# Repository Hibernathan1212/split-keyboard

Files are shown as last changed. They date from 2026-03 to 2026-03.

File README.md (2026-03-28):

# SPlitty

An ergonomic ortholinear split keyboard made to be low profile yet enjoyable and comfortable to use. It features a 6 column by 3 row layout similar to the Corne ergo keyboard but instead with a full width bottom "thumb cluster" that hopefully helps in moving from a traditional keyboard to a split ergo thumb cluster. This is mostly based around many of my current workflows being based around using CMD CTRL and ALT together on my mac so I wanted a way to reliably (no mod tap/hold on home row) press all of them while pressing all the other keys. I have an absolem/voyager style sticking out thumb cluster which allows for a more natural open hand. I wanted to make this project to help with the uncomfortable ergonomics of my desk that make me hunch forward to my keyboard whereas I'd rather my arms be further apart.

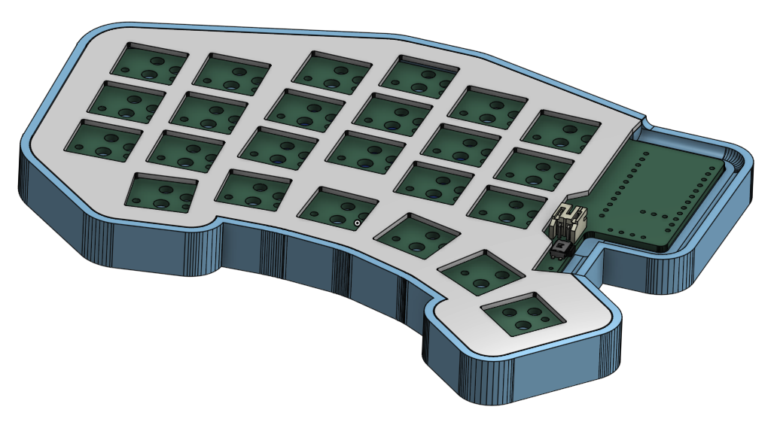
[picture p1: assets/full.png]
full


## Features

- Ortholinear
- Column staggered
- 48 keys
- Pinky splay
- 128x32 OLED Displays
- Customizable tilt with tent legs
- ZMK Firmware
- Low Profile Choc Linear Switches
- Wireless
- Hotswappable

## CAD

Uses a mix between a floating tray mount (resting on top of pillars) and a floating integrated plate on a lip to get the benefits of rigidity from tray mount without being too rigid and also alignment from plate.

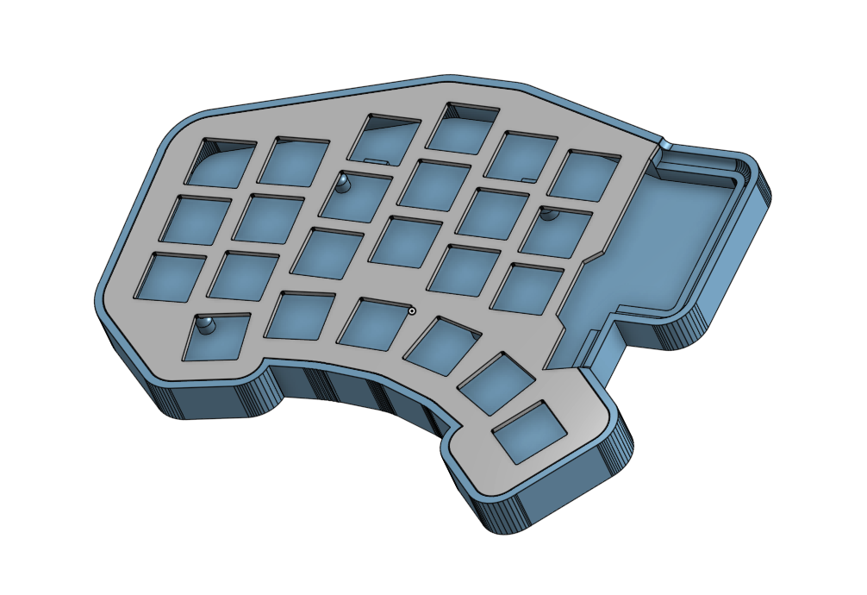
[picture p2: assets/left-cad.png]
Left

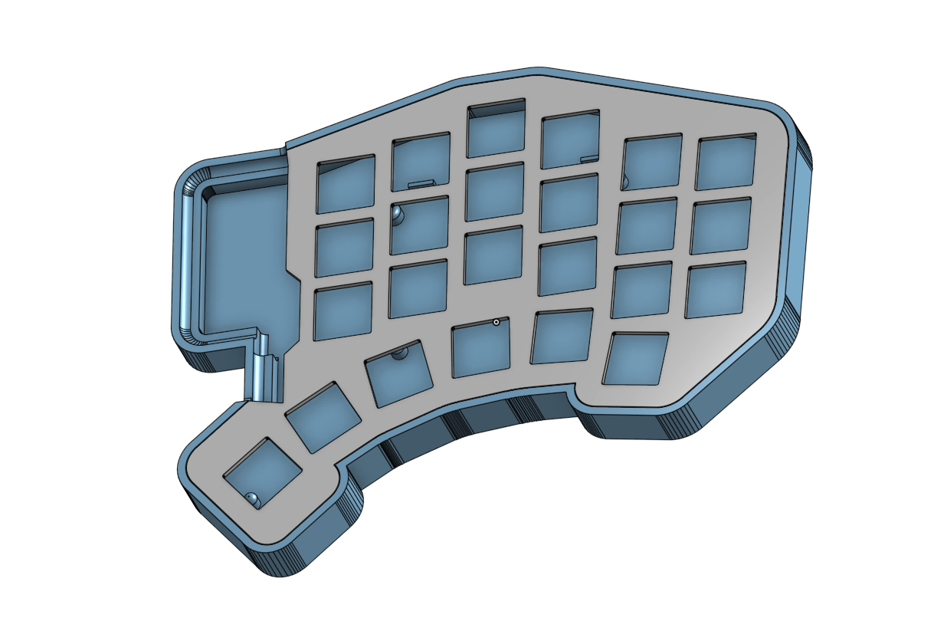
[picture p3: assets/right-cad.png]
Right


Made in Onshape.

## PCB

Made in Kicad

### Schematic

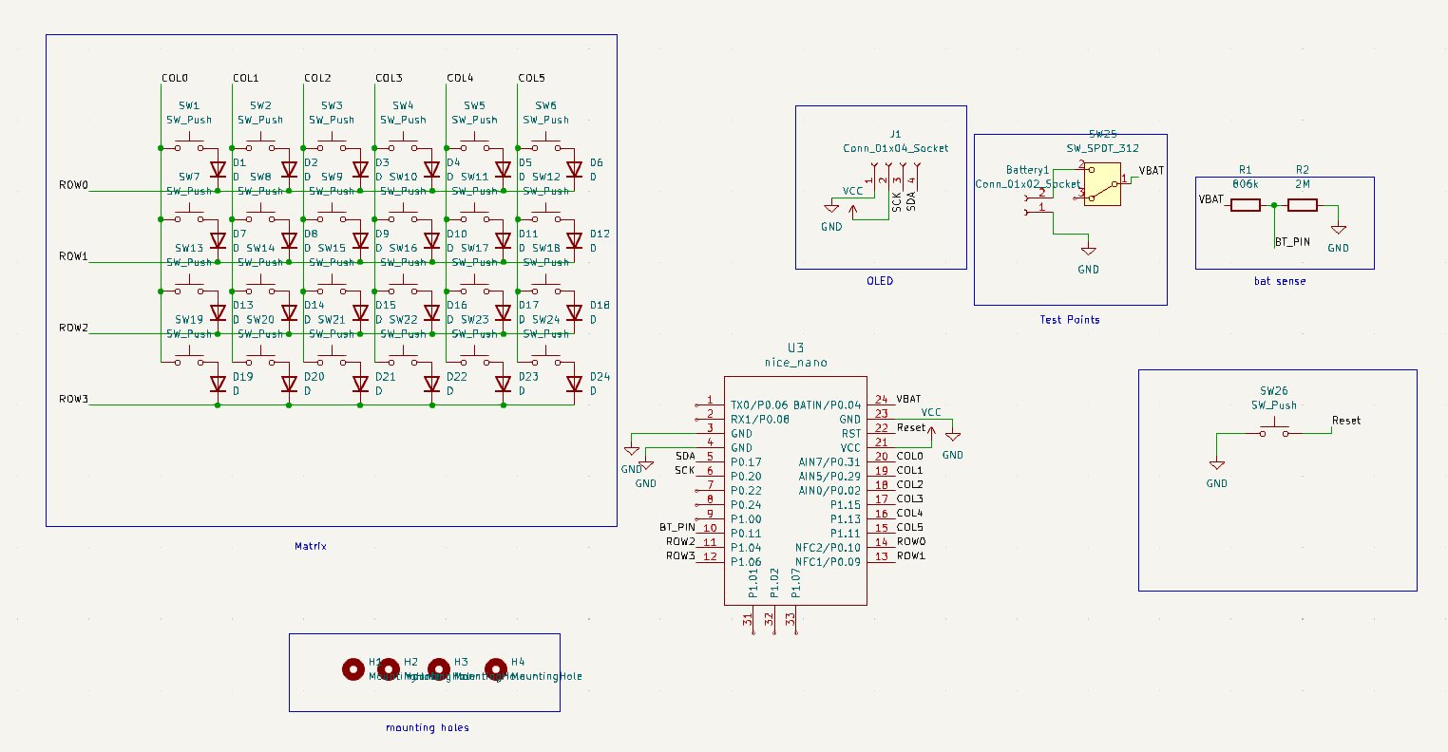
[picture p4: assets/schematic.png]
schematic


### PCB

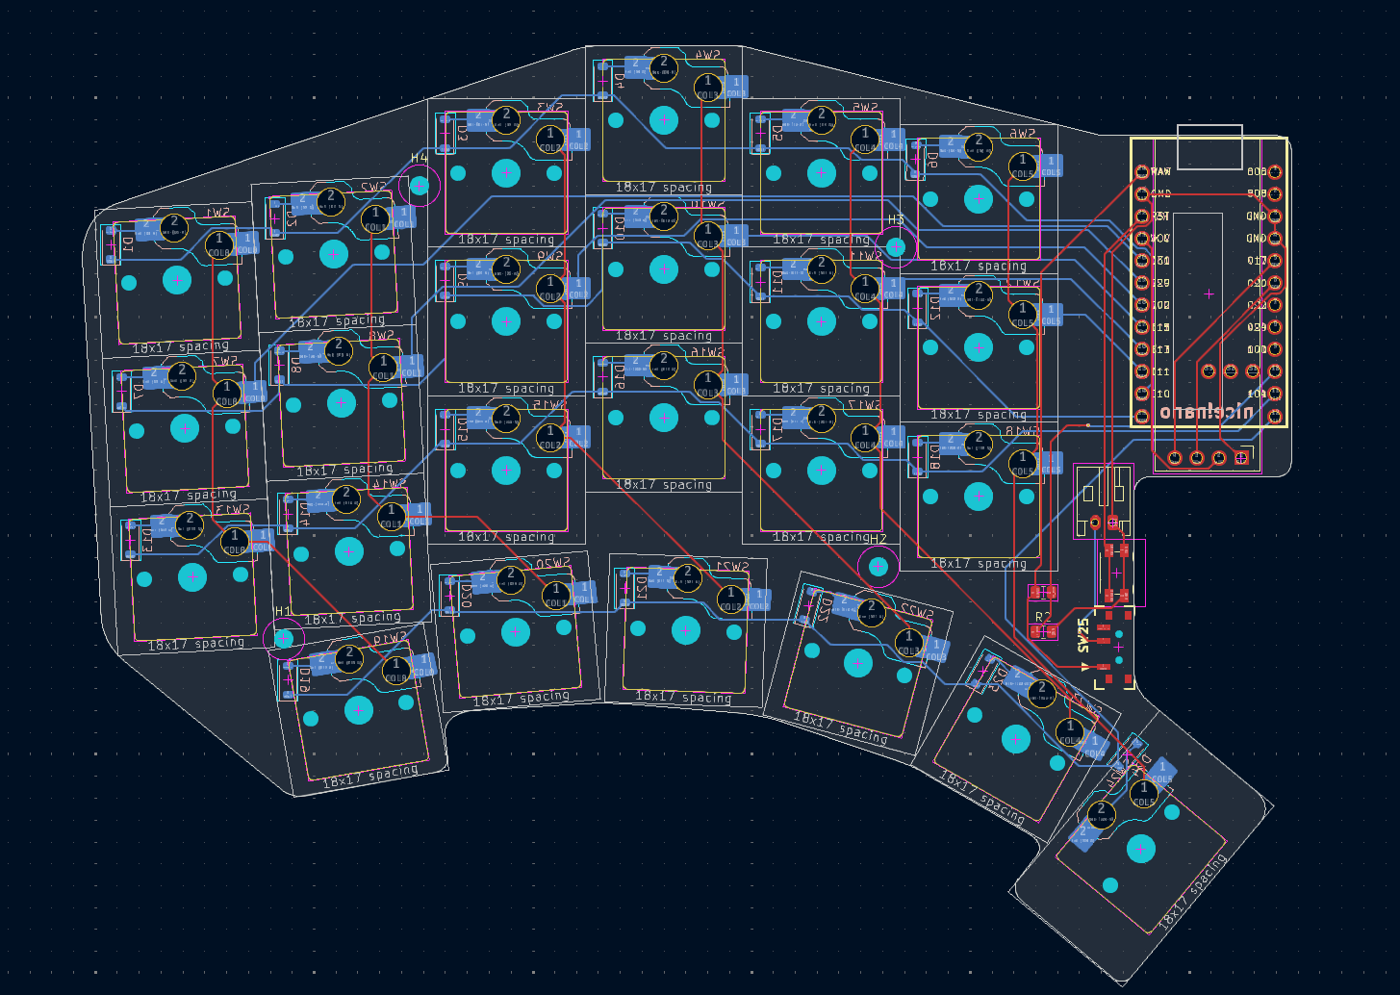
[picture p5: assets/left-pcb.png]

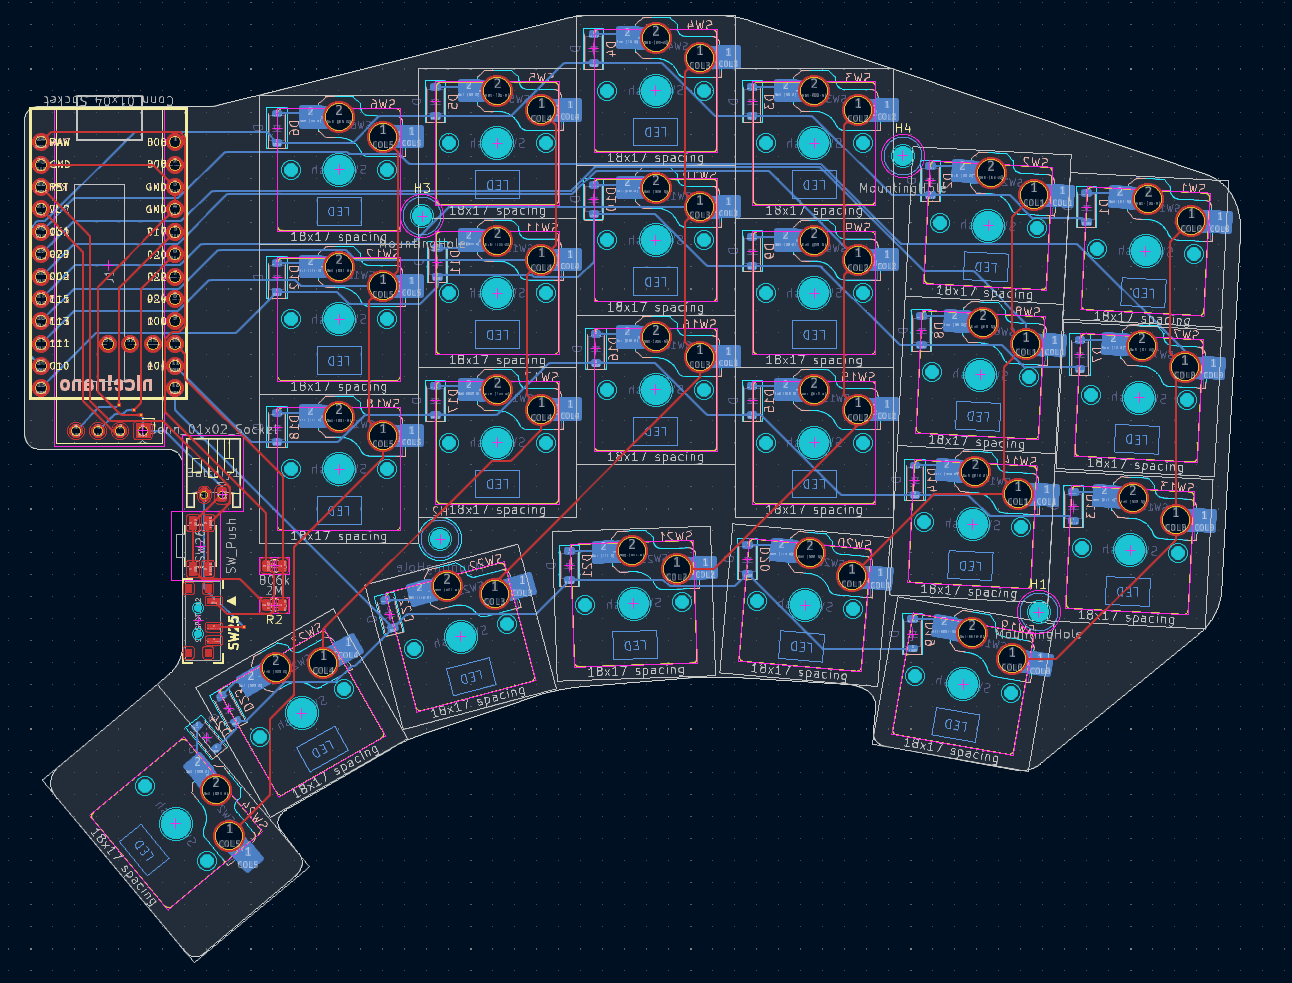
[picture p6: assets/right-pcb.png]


## Firmware

Uses ZMK and is customizable to do whatever you want pretty much. Set up to work with ZMK Studio. By default has 4 layers: the default qwerty layout layer, a numpad & function keys layout, a symbols layer, and a nav layer with mouse movements.

## BOM

| Product | Amount | Unit Cost (THB) | Price (THB) | Price (USD) | Link |
| --- | --- | --- | --- | --- | --- |
| Kailh Choc Low Profile Switches V1  | 70 | 791.58 | 791.58 | 24.09 | [https://th.aliexpress.com/item/1005005723938995.html](https://th.aliexpress.com/item/1005005723938995.html) |
| Kailh Choc Low Profile Keycaps 1u | 5\*10  | 135 | 675 | 20.54 | [https://keebd.com/products/ldsa-low-profile-blank-keycaps?variant=43210374185112](https://keebd.com/products/ldsa-low-profile-blank-keycaps?variant=43210374185112) |
| Kailh Choc Low Profile Keycaps 1.5u | 1\*2 | 51 | 51 | 1.55 | [https://keebd.com/products/ldsa-low-profile-blank-keycaps?variant=43210375397528](https://keebd.com/products/ldsa-low-profile-blank-keycaps?variant=43210375397528) |
| Choc Hotswap Sockets | 50 | 177.03 | 177.03 | 5.39 | [https://th.aliexpress.com/item/1005008543325730.html](https://th.aliexpress.com/item/1005008543325730.html) |
| Reset Button | 2 | 51 | 102 | 3.1 | [https://keebd.com/products/reset-button-panasonic](https://keebd.com/products/reset-button-panasonic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) |
| Power Switch | 2 | 26 | 52 | 1.58 | [https://keebd.com/products/switch-mini-7-pin-2-slide-positions](https://keebd.com/products/switch-mini-7-pin-2-slide-positions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) |
| Rubber Feet | 4 | 73.6 | 73.6 | 2.24 | [https://th.aliexpress.com/item/1005007438396940.html](https://th.aliexpress.com/item/1005007438396940.html) |
| Tenting Feet | 4 | 58.83 | 235.32 | 7.16 | [https://th.aliexpress.com/item/1005011724480659.html](https://th.aliexpress.com/item/1005011724480659.html) |
| 403450 750mAh | 2 | 130.24 | 260.48 | 7.93 | [https://th.aliexpress.com/item/1005003630012646.html](https://th.aliexpress.com/item/1005003630012646.html) |
| Battery JST PH Connector | 2 | 51 | 102 | 3.1 | [https://keebd.com/products/jst-power-connector](https://keebd.com/products/jst-power-connector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) |
| ProMicro nrf52840 Board | 2 | 106.15 | 212.3 | 6.46 | [https://th.aliexpress.com/item/1005006271779544.html](https://th.aliexpress.com/item/1005006271779544.html) |
| Diodes | 1 | 25.78 | 25.78 | 0.78 | [https://th.aliexpress.com/item/1005008826378208.html](https://th.aliexpress.com/item/1005008826378208.html) |
| Oled Display 0.91inch I2C | 1 | 155.34 | 155.34 | 4.73 | [https://th.aliexpress.com/item/1005008918700196.html](https://th.aliexpress.com/item/1005008918700196.html) |
| PCB left | 1 | | | 10 | |
| PCB right | 1 | | | 10 | |
| | | | | | |
| aliexpress shipping | | | 143.8 | 4.38 | |
| keebd shipping | | | 230 | 7 | |
| jlcpcb shipping | | | | 0.05 | |
| | | | | | |
| Total | | | | 120.08 | |

(If anyone could help source cheaper materials it would be greatly appreciated)

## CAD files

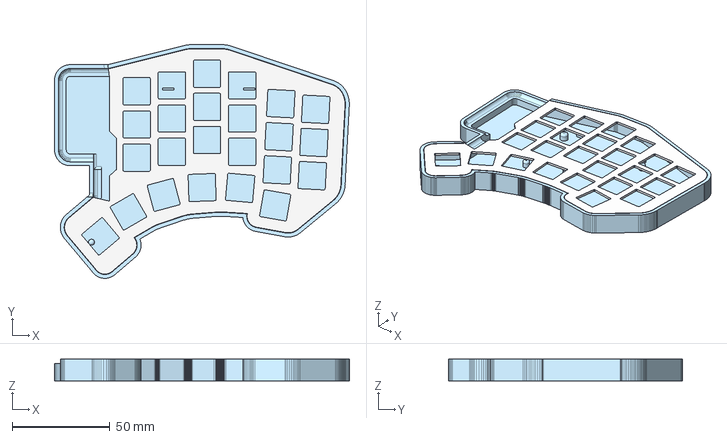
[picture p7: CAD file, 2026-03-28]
cad/assembled right.step
151.0 x 119.7 x 11.2 mm

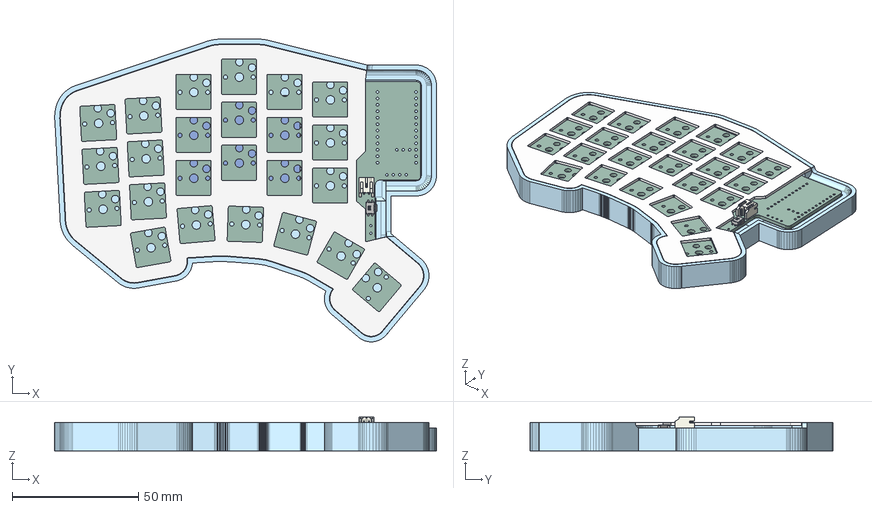
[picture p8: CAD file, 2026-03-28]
cad/Assembled w PCB.step
151.0 x 119.7 x 13.4 mm
D_SOD-123 x 24
R_0805_2012Metric x 2
JST_PH_S2B-PH-K_1x02_P2.00mm_Horizontal
split-keyboard_PCB
Panasonic_EVQPUJ_EVQPUA

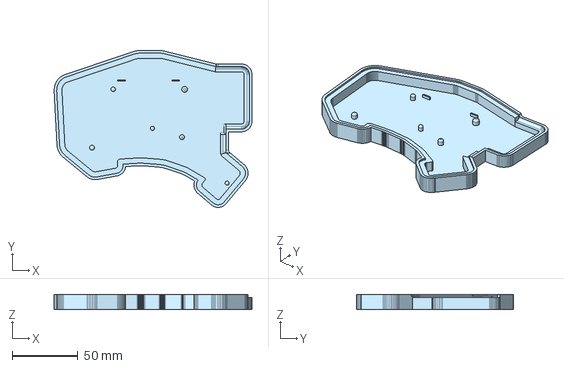
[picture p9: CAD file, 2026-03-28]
production/base left.step
151.0 x 119.7 x 11.2 mm

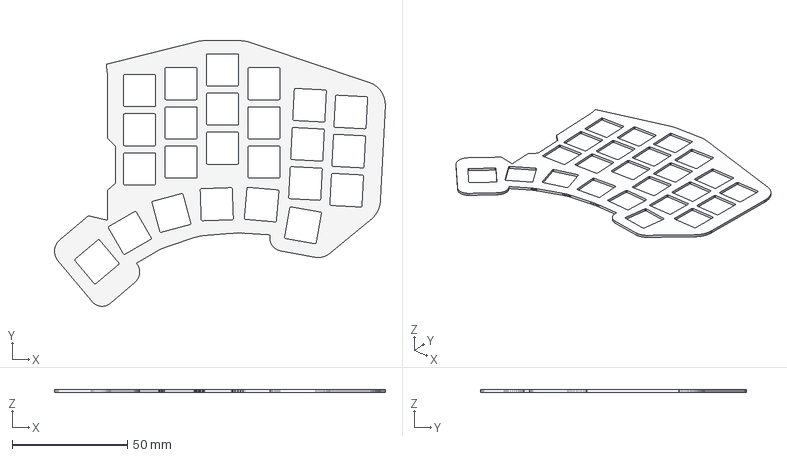
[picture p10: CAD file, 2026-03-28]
production/top right.step
143.7 x 115.3 x 1.20 mm

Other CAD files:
cad/assembled left.step
production/top left.step
production/base right.step

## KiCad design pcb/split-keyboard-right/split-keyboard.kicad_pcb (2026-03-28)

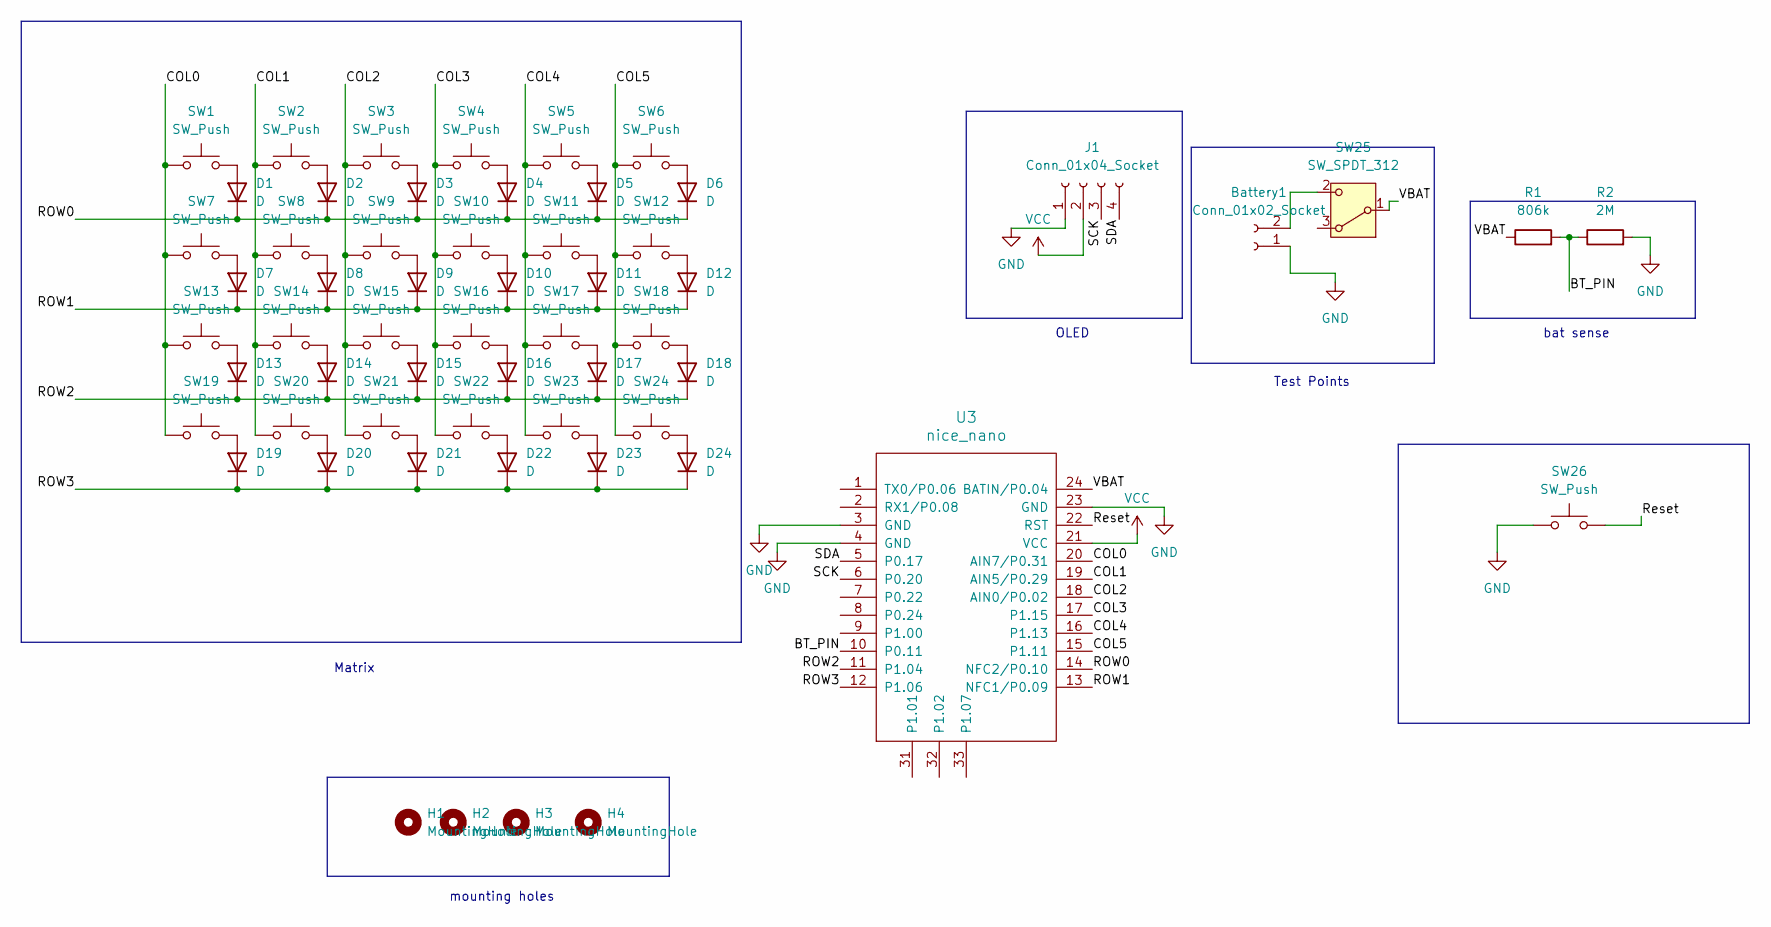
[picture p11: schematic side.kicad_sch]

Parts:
Battery1: Conn_01x02_Socket; JST_PH_S2B-PH-K_1x02_P2.00mm_Horizontal
D1, D2, D3, D4, D5, D6, D7, D8, D9, D10, D11, D12, D13, D14, D15, D16, D17, D18, D19, D20, D21, D22, D23, D24: D; D_SOD-123
H1, H2, H3, H4: MountingHole; MountingHole_2.2mm_M2
J1: Conn_01x04_Socket; ER_OLEDM0.91_1x-I2C
R1: 806k; R_0805_2012Metric
R2: 2M; R_0805_2012Metric
SW1, SW2, SW3, SW4, SW5, SW6, SW7, SW8, SW9, SW10, SW11, SW12, SW13, SW14, SW15, SW16, SW17, SW18, SW19, SW20, SW21, SW22, SW23: SW_Push; SW_choc_v1_HS_CPG135001S30_1u
SW24: SW_Push; SW_choc_v1_HS_CPG135001S30_1.5u
SW25: SW_SPDT_312; ALPS_SSSS811101
SW26: SW_Push; Panasonic_EVQPUJ_EVQPUA
U3: nice_nano

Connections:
/left/BT_PIN: R1.2, R2.1, U3.10 (P0.11)
/left/COL0: SW1.1, SW7.1, SW13.1, SW19.1, U3.20 (AIN7/P0.31)
/left/COL1: SW2.1, SW8.1, SW14.1, SW20.1, U3.19 (AIN5/P0.29)
/left/COL2: SW3.1, SW9.1, SW15.1, SW21.1, U3.18 (AIN0/P0.02)
/left/COL3: SW4.1, SW10.1, SW16.1, SW22.1, U3.17 (P1.15)
/left/COL4: SW5.1, SW11.1, SW17.1, SW23.1, U3.16 (P1.13)
/left/COL5: SW6.1, SW12.1, SW18.1, SW24.1, U3.15 (P1.11)
/left/ROW0: D1.1 (K), D2.1 (K), D3.1 (K), D4.1 (K), D5.1 (K), D6.1 (K), U3.14 (NFC2/P0.10)
/left/ROW1: D7.1 (K), D8.1 (K), D9.1 (K), D10.1 (K), D11.1 (K), D12.1 (K), U3.13 (NFC1/P0.09)
/left/ROW2: D13.1 (K), D14.1 (K), D15.1 (K), D16.1 (K), D17.1 (K), D18.1 (K), U3.11 (P1.04)
/left/ROW3: D19.1 (K), D20.1 (K), D21.1 (K), D22.1 (K), D23.1 (K), D24.1 (K), U3.12 (P1.06)
/left/Reset: SW26.2, U3.22 (RST)
/left/SCK: J1.3, U3.6 (P0.20)
/left/SDA: J1.4, U3.5 (P0.17)
/left/VBAT: R1.1, SW25.1 (B), U3.24 (BATIN/P0.04)
GND: Battery1.1, J1.1, R2.2, SW26.1, U3.3 (GND), U3.4 (GND), U3.23 (GND)
unnamed: Battery1.2, SW25.2 (C)
unnamed: D1.2 (A), SW1.2
unnamed: D2.2 (A), SW2.2
unnamed: D3.2 (A), SW3.2
unnamed: D4.2 (A), SW4.2
unnamed: D5.2 (A), SW5.2
unnamed: D6.2 (A), SW6.2
unnamed: D7.2 (A), SW7.2
unnamed: D8.2 (A), SW8.2
unnamed: D9.2 (A), SW9.2
unnamed: D10.2 (A), SW10.2
unnamed: D11.2 (A), SW11.2
unnamed: D12.2 (A), SW12.2
unnamed: D13.2 (A), SW13.2
unnamed: D14.2 (A), SW14.2
unnamed: D15.2 (A), SW15.2
unnamed: D16.2 (A), SW16.2
unnamed: D17.2 (A), SW17.2
unnamed: D18.2 (A), SW18.2
unnamed: D19.2 (A), SW19.2
unnamed: D20.2 (A), SW20.2
unnamed: D21.2 (A), SW21.2
unnamed: D22.2 (A), SW22.2
unnamed: D23.2 (A), SW23.2
unnamed: D24.2 (A), SW24.2
VCC: J1.2, U3.21 (VCC)

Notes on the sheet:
OLED
Matrix
mounting holes
Test Points
bat sense

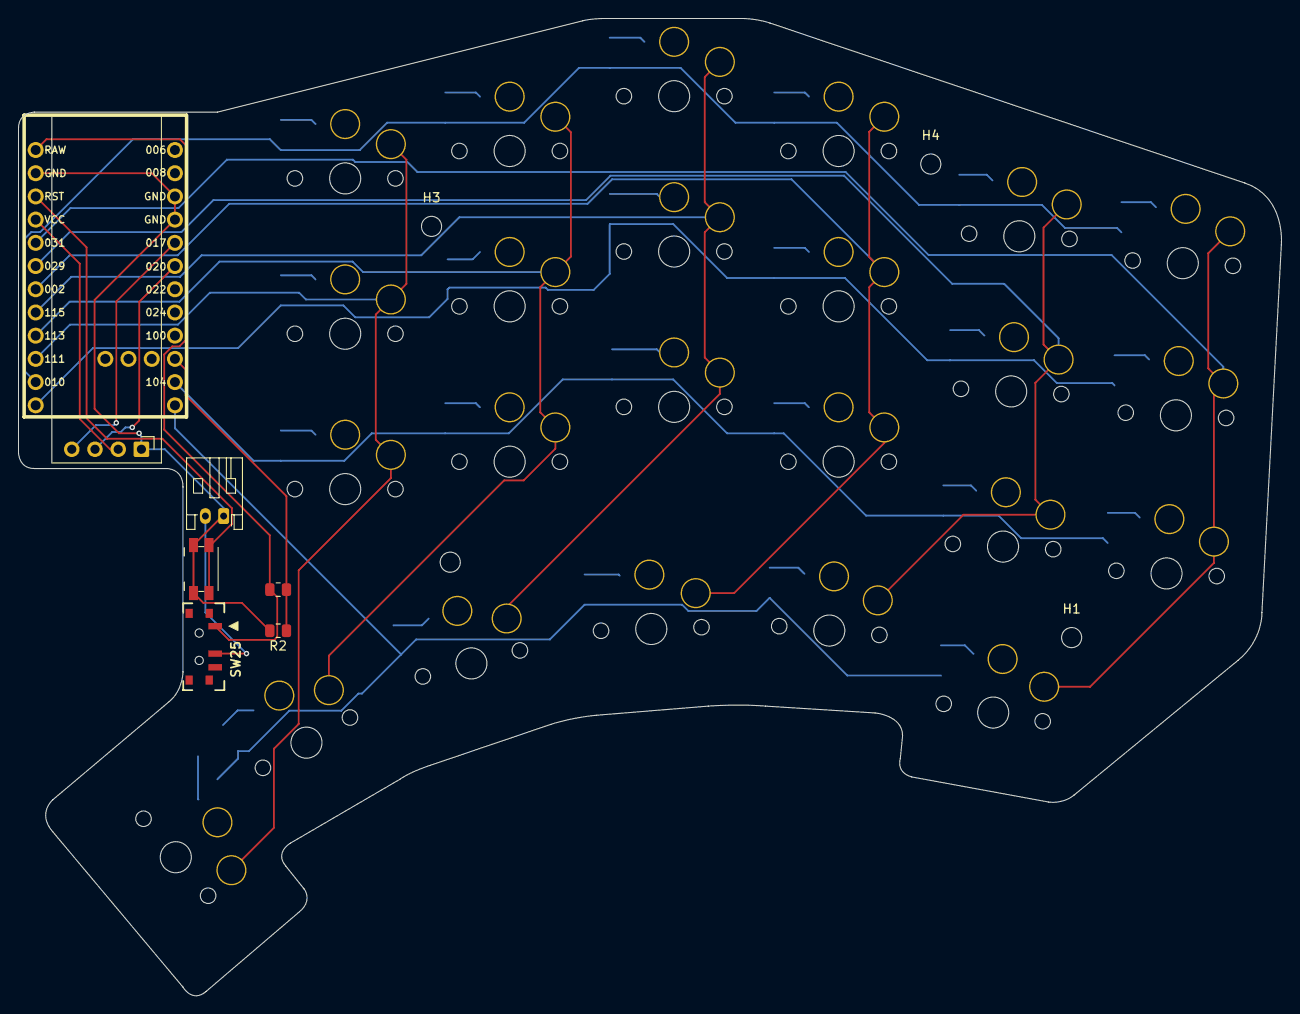
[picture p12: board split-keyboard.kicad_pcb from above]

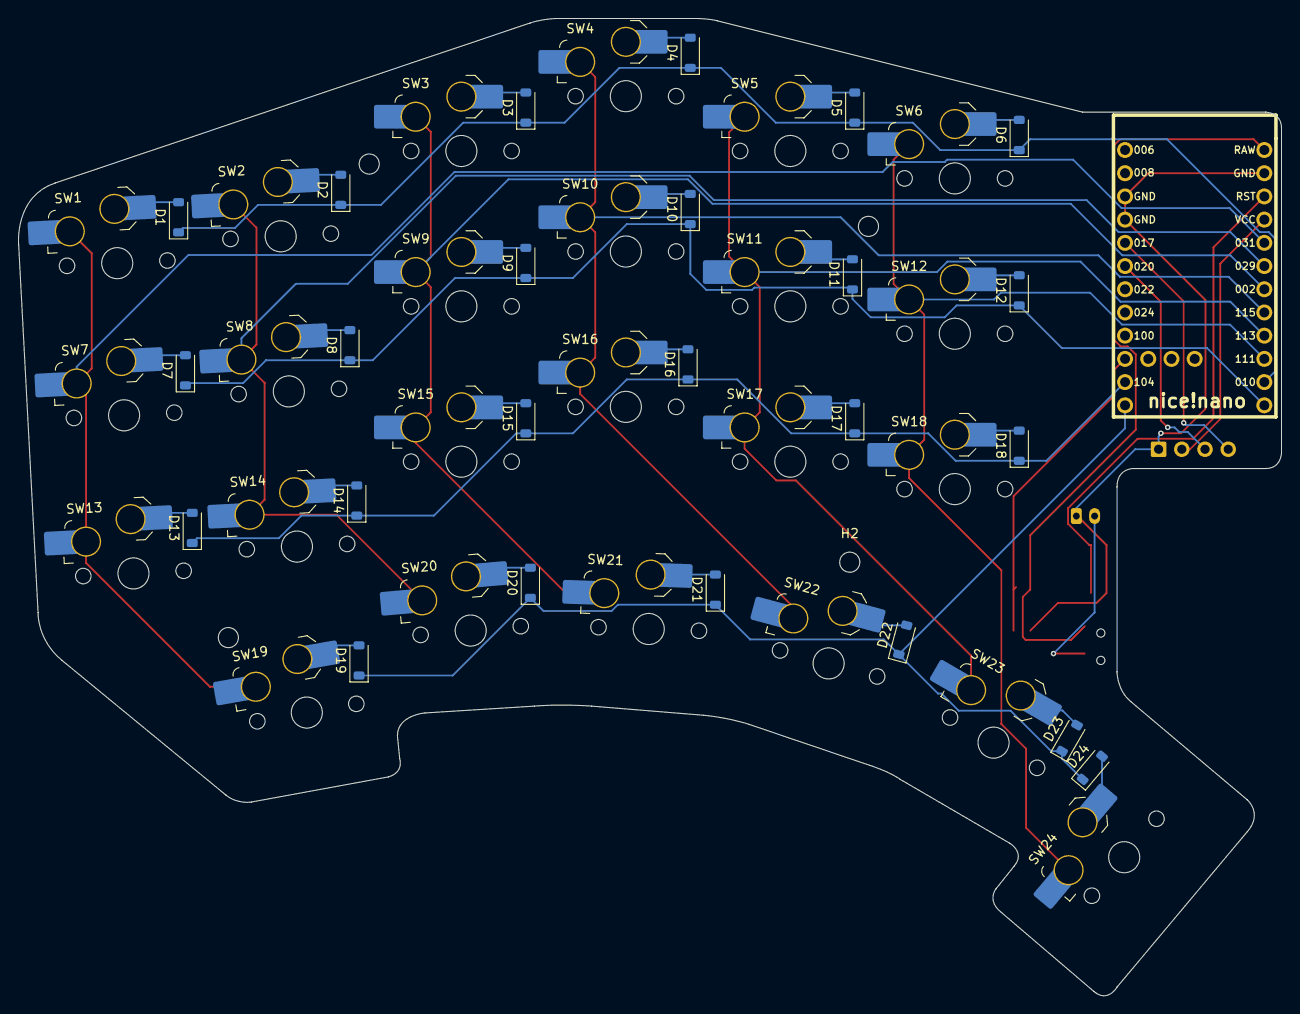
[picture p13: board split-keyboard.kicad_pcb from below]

Board: 2 copper layers, 138.2 x 106.9 mm, 59 parts (50 on the bottom side), 42 nets.
